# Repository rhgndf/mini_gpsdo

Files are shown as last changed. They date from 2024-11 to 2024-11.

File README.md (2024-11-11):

# Mini SI5351 GPSDO

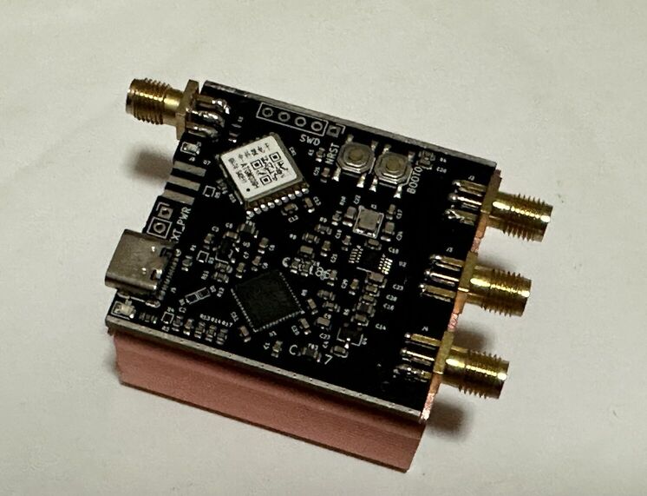
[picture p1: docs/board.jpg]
GPSDO


Features
- VC-TCXO at 10MHz
- SI5351 PLL chip, arbitrary frequency output
- All 3 outputs broken out
- STM32G431 microprocessor
- JLCPCB-assembled
- <25USD each
- Designed to fit a 45cm by 45cm by 18.5cm aluminium enclosure.
- Front and back PCB panels coming soon.

## Manufacturing

Obtain the three files in `hardware/jlcpcb/production_files`

- Upload the gerber to the order page, choose SMT assembly
- Upload the BOM and CPL file in the SMT assembly page.

## Firmware

- If the flash is empty, press the BOOT0 button, then the NRST button and release both, if the firmware is already flashed, you can skip this step.
- Run `dfu-util -a 0 -s 0x08000000:leave -D si5351_gpsdo.bin`
  
### Building

Within the `firmware` folder, run
```
cmake -DCMAKE_TOOLCHAIN_FILE=cubeide-gcc.cmake  -S ./ -B Release -G"Unix Makefiles" -DCMAKE_BUILD_TYPE=Release
make -C Release VERBOSE=1 -j
```

## Configuration
The configuration can be done through the web using [https://rhgndf.github.io/mini_gpsdo/](https://rhgndf.github.io/mini_gpsdo/)

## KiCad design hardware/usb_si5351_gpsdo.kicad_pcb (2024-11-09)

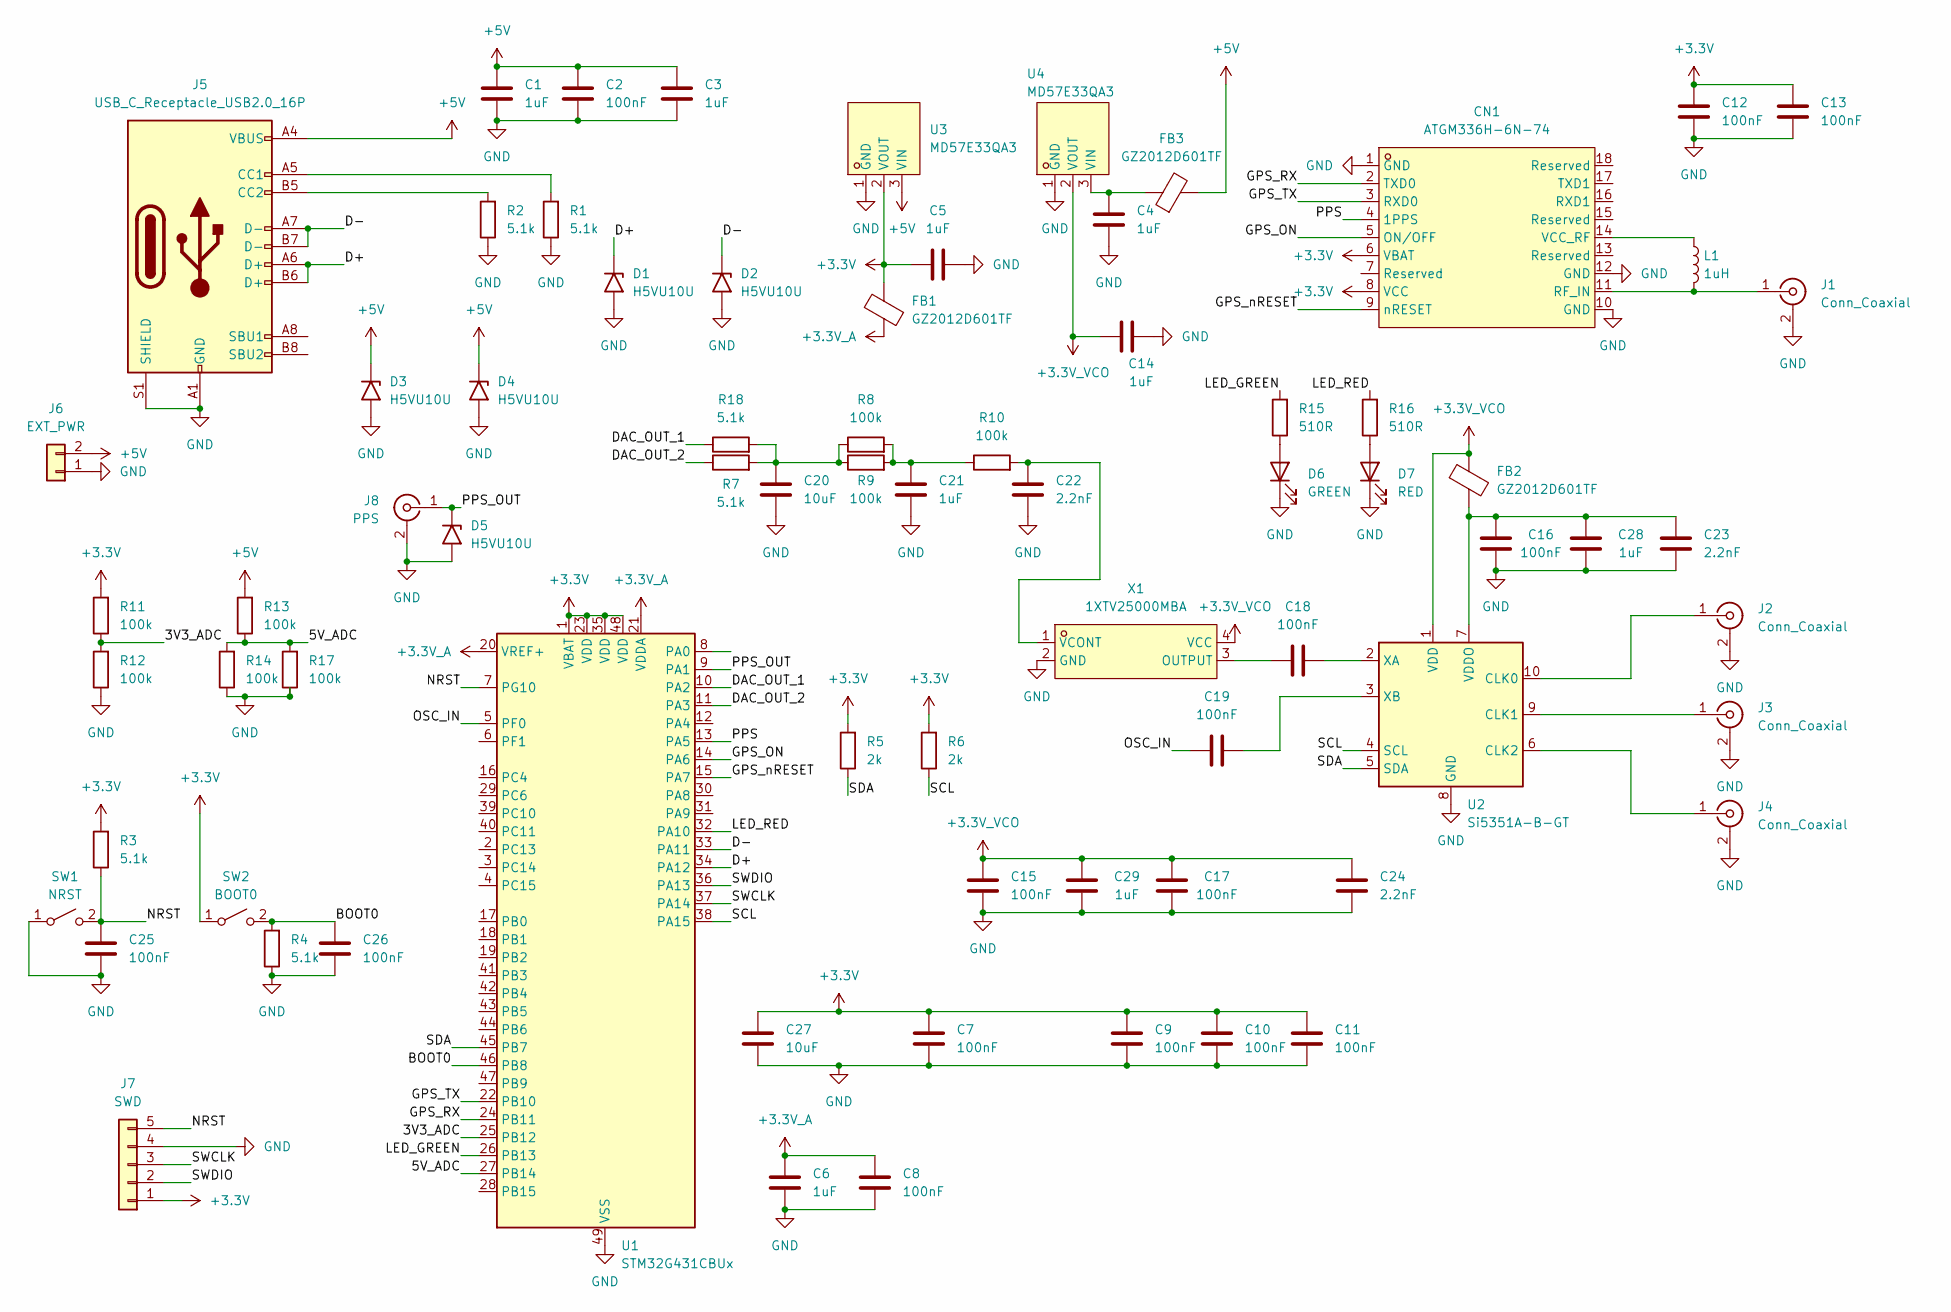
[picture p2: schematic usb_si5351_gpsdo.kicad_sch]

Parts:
C1, C3, C4, C5, C6, C14, C21, C28, C29: 1uF; C_0603_1608Metric
C2, C7, C8, C9, C10, C11, C12, C13, C15, C16, C17, C18, C19, C25, C26: 100nF; C_0603_1608Metric
C20, C27: 10uF; C_0603_1608Metric
C22, C23, C24: 2.2nF; C_0805_2012Metric
CN1: ATGM336H-6N-74; COMM-SMD_18P-L10.1-W9.7-P1.1-TL_L76-LB; LCSC Part C5804601
D1, D2, D3, D4, D5: H5VU10U; D_SOD-882D
D6: GREEN; LED_0805_2012Metric
D7: RED; LED_0603_1608Metric
FB1, FB2, FB3: GZ2012D601TF; L_0805_2012Metric
J1, J2, J3, J4: Conn_Coaxial; SMA-SMD_BWSMA-KE-P001
J5: USB_C_Receptacle_USB2.0_16P; USB-C-SMD_TYPE-C16PIN
J6: EXT_PWR; PinHeader_1x02_P2.54mm_Vertical
J7: SWD; PinHeader_1x05_P2.54mm_Vertical
J8: PPS; SMA-SMD_BWSMA-KE-P001
L1: 1uH; L_0805_2012Metric
R1, R2, R3, R4, R7, R18: 5.1k; R_0603_1608Metric
R5, R6: 2k; R_0603_1608Metric
R8, R9, R10, R11, R12, R13, R14, R17: 100k; R_0603_1608Metric
R15, R16: 510R; R_0603_1608Metric
SW1: NRST; SW-SMD_4P-L5.1-W5.1-P3.70-LS6.5-TL-2
SW2: BOOT0; SW-SMD_4P-L5.1-W5.1-P3.70-LS6.5-TL-2
U1: STM32G431CBUx; QFN-48-1EP_7x7mm_P0.5mm_EP5.6x5.6mm
U2: Si5351A-B-GT; MSOP-10_3x3mm_P0.5mm
U3, U4: MD57E33QA3; SOT-23-3_L2.9-W1.6-P1.90-LS2.8-BR; LCSC Part C920553
X1: 1XTV25000MBA; OSC-SMD_4P-L3.2-W2.5-BL; LCSC Part C253674

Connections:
+3.3V: C5.1, C7.1, C9.1, C10.1, C11.1, C12.1, C13.1, C27.1, CN1.6 (VBAT), CN1.8 (VCC), FB1.2, J7.1, R3.2, R5.2, R6.2, R11.2, SW2.1 (A), U1.1 (VBAT), U1.23 (VDD), U1.35 (VDD), U1.48 (VDD), U3.2 (VOUT)
+3.3V_A: C6.1, C8.1, FB1.1, U1.20 (VREF+), U1.21 (VDDA)
+3.3V_VCO: C14.1, C15.1, C17.2, C24.1, C29.1, FB2.1, U2.1 (VDD), U4.2 (VOUT), X1.4 (VCC)
+5V: C1.1, C2.1, C3.1, D3.1 (A1), D4.1 (A1), FB3.2, J5.A4 (VBUS), J5.A9 (VBUS), J5.B4 (VBUS), J5.B9 (VBUS), J6.2, R13.2, U3.3 (VIN)
/3V3_ADC: R11.1, R12.2, U1.25 (PB12)
/5V_ADC: R13.1, R14.2, R17.2, U1.27 (PB14)
/BOOT0: C26.2, R4.2, SW2.2 (B), U1.46 (PB8)
/D+: D1.1 (A1), J5.A6 (D+), J5.B6 (D+), U1.34 (PA12)
/D-: D2.1 (A1), J5.A7 (D-), J5.B7 (D-), U1.33 (PA11)
/DAC_OUT_1: R18.1, U1.10 (PA2)
/DAC_OUT_2: R7.1, U1.11 (PA3)
/GPS_ON: CN1.5 (ON/OFF), U1.14 (PA6)
/GPS_RX: CN1.2 (TXD0), U1.24 (PB11)
/GPS_TX: CN1.3 (RXD0), U1.22 (PB10)
/GPS_nRESET: CN1.9 (nRESET), U1.15 (PA7)
/LED_GREEN: R15.2, U1.26 (PB13)
/LED_RED: R16.2, U1.32 (PA10)
/NRST: C25.2, J7.5, R3.1, SW1.2 (B), U1.7 (PG10)
/OSC_IN: C19.1, U1.5 (PF0)
/PPS: CN1.4 (1PPS), U1.13 (PA5)
/PPS_OUT: D5.1 (A1), J8.1 (In), U1.9 (PA1)
/SCL: R6.1, U1.38 (PA15), U2.4 (SCL)
/SDA: R5.1, U1.45 (PB7), U2.5 (SDA)
/SWCLK: J7.3, U1.37 (PA14)
/SWDIO: J7.2, U1.36 (PA13)
GND: C1.2, C2.2, C3.2, C4.2, C5.2, C6.2, C7.2, C8.2, C9.2, C10.2, C11.2, C12.2, C13.2, C14.2, C15.2, C16.2, C17.1, C20.2, C21.2, C22.2, C23.2, C24.2, C25.1, C26.1, C27.2, C28.2, C29.2, CN1.1 (GND), CN1.10 (GND), CN1.12 (GND), D1.2 (A2), D2.2 (A2), D3.2 (A2), D4.2 (A2), D5.2 (A2), D6.1 (K), D7.1 (K), J1.2 (Ext), J2.2 (Ext), J3.2 (Ext), J4.2 (Ext), J5.A1 (GND), J5.A12 (GND), J5.B1 (GND), J5.B12 (GND), J5.S1 (SHIELD), J6.1, J7.4, J8.2 (Ext), R1.1, R2.1, R4.1, R12.1, R14.1, R17.1, SW1.1 (A), U1.49 (VSS), U2.8 (GND), U3.1 (GND), U4.1 (GND), X1.2 (GND)
unnamed: C20.1, R7.2, R8.1, R9.1, R18.2
unnamed: C21.1, R8.2, R9.2, R10.1
unnamed: CN1.11 (RF_IN), J1.1 (In), L1.2
unnamed: CN1.14 (VCC_RF), L1.1
unnamed: D6.2 (A), R15.1
unnamed: D7.2 (A), R16.1
unnamed: J2.1 (In), U2.10 (CLK0)
unnamed: J3.1 (In), U2.9 (CLK1)
unnamed: J4.1 (In), U2.6 (CLK2)
unnamed: J5.A5 (CC1), R1.2
unnamed: J5.B5 (CC2), R2.2
unnamed: C16.1, C23.1, C28.1, FB2.2, U2.7 (VDDO)
unnamed: C18.2, U2.2 (XA)
unnamed: C19.2, U2.3 (XB)
unnamed: C4.1, FB3.1, U4.3 (VIN)
unnamed: C18.1, X1.3 (OUTPUT)
unnamed: C22.1, R10.2, X1.1 (VCONT)

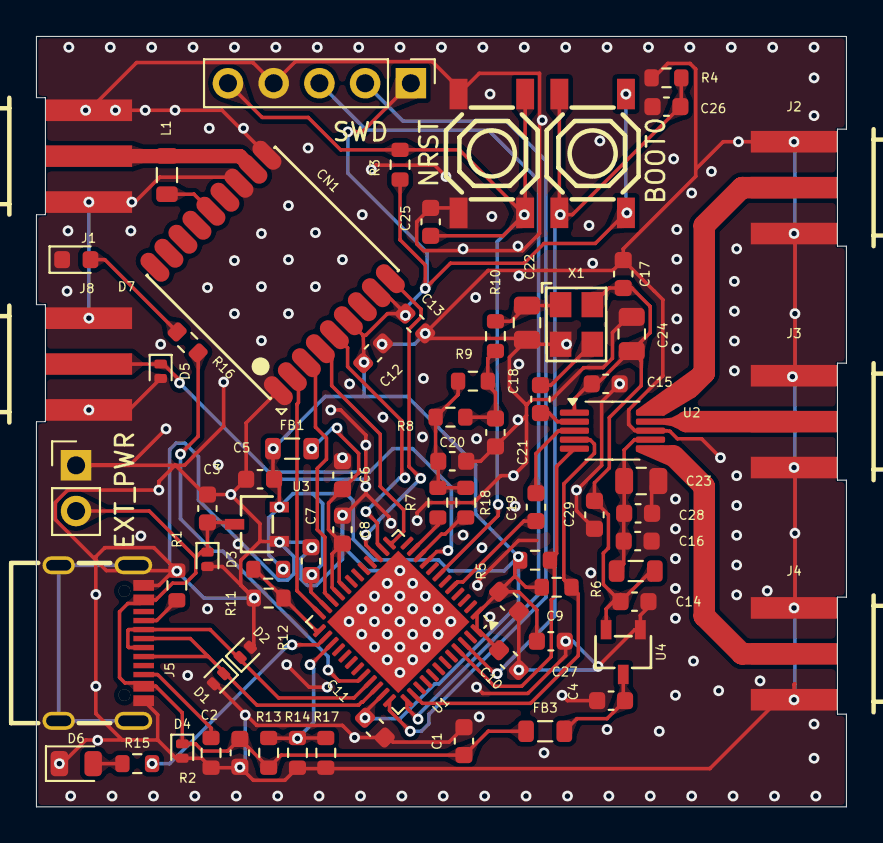
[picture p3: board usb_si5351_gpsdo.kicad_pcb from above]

Board: 2 copper layers, 45.0 x 42.8 mm, 74 parts (0 on the bottom side), 43 nets.

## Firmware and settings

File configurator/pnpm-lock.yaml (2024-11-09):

lockfileVersion: '9.0'

settings:
  autoInstallPeers: true
  excludeLinksFromLockfile: false

importers:

  .:
    dependencies:
      alpinejs:
        specifier: ^3.14.3
        version: 3.14.3
    devDependencies:
      autoprefixer:
        specifier: ^10.4.20
        version: 10.4.20(postcss@8.4.47)
      parcel:
        specifier: ^2.12.0
        version: 2.12.0(@swc/helpers@0.5.13)(postcss@8.4.47)
      postcss:
        specifier: ^8.4.47
        version: 8.4.47
      tailwindcss:
        specifier: ^3.4.14
        version: 3.4.14

packages:

  '@alloc/quick-lru@5.2.0':
    resolution: {integrity: sha512-UrcABB+4bUrFABwbluTIBErXwvbsU/V7TZWfmbgJfbkwiBuziS9gxdODUyuiecfdGQ85jglMW6juS3+z5TsKLw==}
    engines: {node: '>=10'}

  '@babel/code-frame@7.26.2':
    resolution: {integrity: sha512-RJlIHRueQgwWitWgF8OdFYGZX328Ax5BCemNGlqHfplnRT9ESi8JkFlvaVYbS+UubVY6dpv87Fs2u5M29iNFVQ==}
    engines: {node: '>=6.9.0'}

  '@babel/helper-validator-identifier@7.25.9':
    resolution: {integrity: sha512-Ed61U6XJc3CVRfkERJWDz4dJwKe7iLmmJsbOGu9wSloNSFttHV0I8g6UAgb7qnK5ly5bGLPd4oXZlxCdANBOWQ==}
    engines: {node: '>=6.9.0'}

  '@isaacs/cliui@8.0.2':
    resolution: {integrity: sha512-O8jcjabXaleOG9DQ0+ARXWZBTfnP4WNAqzuiJK7ll44AmxGKv/J2M4TPjxjY3znBCfvBXFzucm1twdyFybFqEA==}
    engines: {node: '>=12'}

  '@jridgewell/gen-mapping@0.3.5':
    resolution: {integrity: sha512-IzL8ZoEDIBRWEzlCcRhOaCupYyN5gdIK+Q6fbFdPDg6HqX6jpkItn7DFIpW9LQzXG6Df9sA7+OKnq0qlz/GaQg==}
    engines: {node: '>=6.0.0'}

  '@jridgewell/resolve-uri@3.1.2':
    resolution: {integrity: sha512-bRISgCIjP20/tbWSPWMEi54QVPRZExkuD9lJL+UIxUKtwVJA8wW1Trb1jMs1RFXo1CBTNZ/5hpC9QvmKWdopKw==}
    engines: {node: '>=6.0.0'}

  '@jridgewell/set-array@1.2.1':
    resolution: {integrity: sha512-R8gLRTZeyp03ymzP/6Lil/28tGeGEzhx1q2k703KGWRAI1VdvPIXdG70VJc2pAMw3NA6JKL5hhFu1sJX0Mnn/A==}
    engines: {node: '>=6.0.0'}

  '@jridgewell/sourcemap-codec@1.5.0':
    resolution: {integrity: sha512-gv3ZRaISU3fjPAgNsriBRqGWQL6quFx04YMPW/zD8XMLsU32mhCCbfbO6KZFLjvYpCZ8zyDEgqsgf+PwPaM7GQ==}

  '@jridgewell/trace-mapping@0.3.25':
    resolution: {integrity: sha512-vNk6aEwybGtawWmy/PzwnGDOjCkLWSD2wqvjGGAgOAwCGWySYXfYoxt00IJkTF+8Lb57DwOb3Aa0o9CApepiYQ==}

  '@lezer/common@1.2.3':
    resolution: {integrity: sha512-w7ojc8ejBqr2REPsWxJjrMFsA/ysDCFICn8zEOR9mrqzOu2amhITYuLD8ag6XZf0CFXDrhKqw7+tW8cX66NaDA==}

  '@lezer/lr@1.4.2':
    resolution: {integrity: sha512-pu0K1jCIdnQ12aWNaAVU5bzi7Bd1w54J3ECgANPmYLtQKP0HBj2cE/5coBD66MT10xbtIuUr7tg0Shbsvk0mDA==}

  '@lmdb/lmdb-darwin-arm64@2.8.5':
    resolution: {integrity: sha512-KPDeVScZgA1oq0CiPBcOa3kHIqU+pTOwRFDIhxvmf8CTNvqdZQYp5cCKW0bUk69VygB2PuTiINFWbY78aR2pQw==}
    cpu: [arm64]
    os: [darwin]

  '@lmdb/lmdb-darwin-x64@2.8.5':
    resolution: {integrity: sha512-w/sLhN4T7MW1nB3R/U8WK5BgQLz904wh+/SmA2jD8NnF7BLLoUgflCNxOeSPOWp8geP6nP/+VjWzZVip7rZ1ug==}
    cpu: [x64]
    os: [darwin]

  '@lmdb/lmdb-linux-arm64@2.8.5':
    resolution: {integrity: sha512-vtbZRHH5UDlL01TT5jB576Zox3+hdyogvpcbvVJlmU5PdL3c5V7cj1EODdh1CHPksRl+cws/58ugEHi8bcj4Ww==}
    cpu: [arm64]
    os: [linux]

  '@lmdb/lmdb-linux-arm@2.8.5':
    resolution: {integrity: sha512-c0TGMbm2M55pwTDIfkDLB6BpIsgxV4PjYck2HiOX+cy/JWiBXz32lYbarPqejKs9Flm7YVAKSILUducU9g2RVg==}
    cpu: [arm]
    os: [linux]

  '@lmdb/lmdb-linux-x64@2.8.5':
    resolution: {integrity: sha512-Xkc8IUx9aEhP0zvgeKy7IQ3ReX2N8N1L0WPcQwnZweWmOuKfwpS3GRIYqLtK5za/w3E60zhFfNdS+3pBZPytqQ==}
    cpu: [x64]
    os: [linux]

  '@lmdb/lmdb-win32-x64@2.8.5':
    resolution: {integrity: sha512-4wvrf5BgnR8RpogHhtpCPJMKBmvyZPhhUtEwMJbXh0ni2BucpfF07jlmyM11zRqQ2XIq6PbC2j7W7UCCcm1rRQ==}
    cpu: [x64]
    os: [win32]

  '@mischnic/json-sourcemap@0.1.1':
    resolution: {integrity: sha512-iA7+tyVqfrATAIsIRWQG+a7ZLLD0VaOCKV2Wd/v4mqIU3J9c4jx9p7S0nw1XH3gJCKNBOOwACOPYYSUu9pgT+w==}
    engines: {node: '>=12.0.0'}

  '@msgpackr-extract/msgpackr-extract-darwin-arm64@3.0.3':
    resolution: {integrity: sha512-QZHtlVgbAdy2zAqNA9Gu1UpIuI8Xvsd1v8ic6B2pZmeFnFcMWiPLfWXh7TVw4eGEZ/C9TH281KwhVoeQUKbyjw==}
    cpu: [arm64]
    os: [darwin]

  '@msgpackr-extract/msgpackr-extract-darwin-x64@3.0.3':
    resolution: {integrity: sha512-mdzd3AVzYKuUmiWOQ8GNhl64/IoFGol569zNRdkLReh6LRLHOXxU4U8eq0JwaD8iFHdVGqSy4IjFL4reoWCDFw==}
    cpu: [x64]
    os: [darwin]

  '@msgpackr-extract/msgpackr-extract-linux-arm64@3.0.3':
    resolution: {integrity: sha512-YxQL+ax0XqBJDZiKimS2XQaf+2wDGVa1enVRGzEvLLVFeqa5kx2bWbtcSXgsxjQB7nRqqIGFIcLteF/sHeVtQg==}
    cpu: [arm64]
    os: [linux]

  '@msgpackr-extract/msgpackr-extract-linux-arm@3.0.3':
    resolution: {integrity: sha512-fg0uy/dG/nZEXfYilKoRe7yALaNmHoYeIoJuJ7KJ+YyU2bvY8vPv27f7UKhGRpY6euFYqEVhxCFZgAUNQBM3nw==}
    cpu: [arm]
    os: [linux]

  '@msgpackr-extract/msgpackr-extract-linux-x64@3.0.3':
    resolution: {integrity: sha512-cvwNfbP07pKUfq1uH+S6KJ7dT9K8WOE4ZiAcsrSes+UY55E/0jLYc+vq+DO7jlmqRb5zAggExKm0H7O/CBaesg==}
    cpu: [x64]
    os: [linux]
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

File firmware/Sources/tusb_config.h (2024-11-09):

/*
 * The MIT License (MIT)
 *
 * Copyright (c) 2019 Ha Thach (tinyusb.org)
 *
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
 */

#ifndef _TUSB_CONFIG_H_
#define _TUSB_CONFIG_H_

#ifdef __cplusplus
 extern "C" {
#endif

//--------------------------------------------------------------------+
// Board Specific Configuration
//--------------------------------------------------------------------+

// RHPort number used for device can be defined by board.mk, default to port 0
#ifndef BOARD_TUD_RHPORT
#define BOARD_TUD_RHPORT      0
#endif

// RHPort max operational speed can defined by board.mk
#ifndef BOARD_TUD_MAX_SPEED
#define BOARD_TUD_MAX_SPEED   OPT_MODE_FULL_SPEED
#endif

//--------------------------------------------------------------------
// COMMON CONFIGURATION
//--------------------------------------------------------------------

// defined by board.mk
#ifndef CFG_TUSB_MCU
#error CFG_TUSB_MCU must be defined
#endif

#ifndef CFG_TUSB_OS
#define CFG_TUSB_OS           OPT_OS_NONE
#endif

#ifndef CFG_TUSB_DEBUG
#define CFG_TUSB_DEBUG        0
#endif

// Enable Device stack
#define CFG_TUD_ENABLED       1

// Default is max speed that hardware controller could support with on-chip PHY
#define CFG_TUD_MAX_SPEED     BOARD_TUD_MAX_SPEED

#define TUD_OPT_RHPORT       BOARD_TUD_RHPORT
/* USB DMA on some MCUs can only access a specific SRAM region with restriction on alignment.
 * Tinyusb use follows macros to declare transferring memory so that they can be put
 * into those specific section.
 * e.g
 * - CFG_TUSB_MEM SECTION : __attribute__ (( section(".usb_ram") ))
 * - CFG_TUSB_MEM_ALIGN   : __attribute__ ((aligned(4)))
 */
#ifndef CFG_TUSB_MEM_SECTION
#define CFG_TUSB_MEM_SECTION
#endif

#ifndef CFG_TUSB_MEM_ALIGN
#define CFG_TUSB_MEM_ALIGN          __attribute__ ((aligned(4)))
#endif

//--------------------------------------------------------------------
// DEVICE CONFIGURATION
//--------------------------------------------------------------------

#ifndef CFG_TUD_ENDPOINT0_SIZE
#define CFG_TUD_ENDPOINT0_SIZE    64
#endif

//------------- CLASS -------------//
#define CFG_TUD_CDC               2
#define CFG_TUD_DFU_RUNTIME       1
#define CFG_TUD_MSC               0
#define CFG_TUD_HID               0
#define CFG_TUD_MIDI              0
#define CFG_TUD_VENDOR            1

// CDC FIFO size of TX and RX
#define CFG_TUD_CDC_RX_BUFSIZE      128
#define CFG_TUD_CDC_TX_BUFSIZE      128

// CDC Endpoint transfer buffer size, more is faster
#define CFG_TUD_CDC_EP_BUFSIZE      64

#define CFG_TUD_VENDOR_RX_BUFSIZE   64
#define CFG_TUD_VENDOR_TX_BUFSIZE   64

#ifdef __cplusplus
 }
#endif

#endif /* _TUSB_CONFIG_H_ */
